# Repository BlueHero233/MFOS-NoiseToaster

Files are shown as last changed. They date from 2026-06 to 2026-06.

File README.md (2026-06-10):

# MFOS Noise Toaster

> ##### Forked from *[Tom Obvious][(https://github.com/Tom-Obvious/MFOS-NoiseToaster)]*

## Status

WIP - working out flaws from Tom's design choices

## Motivation

My first eletronics project, like, at all.
This repository is for the documentation of the changes im currently making to the Rev 6.1 of Tom's design, to better fit with at hand materials and more modern/cheaper components.
Components like the 2N5457 or the LM386N-4 arent exactly easy to find or cheap to buy, moving foward id like to do a circuit analysis of Ray's original circuit to determine if i can swap some pieces out for more common components that arent going out of production anytime soon 

## How to use this repository

This repository contains all the files necessary for building the Noise Toaster, including the synth's PCB.  
If you intend to create your own PCB, simply compress all the files located in the 'PCB/Gerber Files' directory into a .zip file and upload it to the PCB manufacturer of your choice.   
In the directories 'classic design' are all files to build the case of the Noise Toaster.    
For the front panels, I also created PCB designs, which you can upload to a manifacturer. Furthermore, there are CAD files and technical drawings (yet to come!) in the folders.   
The 'src' folder contains additional files which might be helpful.

## Project Structure
MFOS-NoiseToaster/  
  'src/' additional files and images that might be helpful for your own build   
  'classic design/'__ &rarr; all files to build the classic Noise Toaster case   
  'CAD/'
    '.FCstd' &rarr; FreeCAD files for the build    
  'front panel/'
    '.pro' &rarr; KiCAD files for front panel PCB
  'PCB/'
    'Gerber' *Generate this folder yourself!* &rarr; .zip this directory for upload to the manufacturer    
    'Noise Toaster PCB.kicad_pro' &rarr; opening the project file will also open all the subschematics and pcb
    'bom/' 
      'BoM checklist.md'  
      'interactive BOM.html' 
  'src/'
  'README.md'
  'licence.md' &rarr; CC-BY-NC-SA

## Usefull links and resources

* [Music From Outer Space](http://musicfromouterspace.com/)
* [MFOS - Noise Toaster - Documentation](http://musicfromouterspace.com/index.php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)
* [Ray Wilson - YouTube Channel](https://www.youtube.com/@Musicfromouterspace)
* [MFOS Noise Toaster Presentation - Video by Ray Wilson](https://www.youtube.com/watch?v=smFKx6gfOd0)
* [Noise Toaster in action - Video by Ray Wilson](https://www.youtube.com/watch?v=qHlyuIe3wuU)
* [Make: Analog Synthesizers by Ray Wilson](https://learning.oreilly.com/library/view/make-analog-synthesizers/9781449356200/)

---


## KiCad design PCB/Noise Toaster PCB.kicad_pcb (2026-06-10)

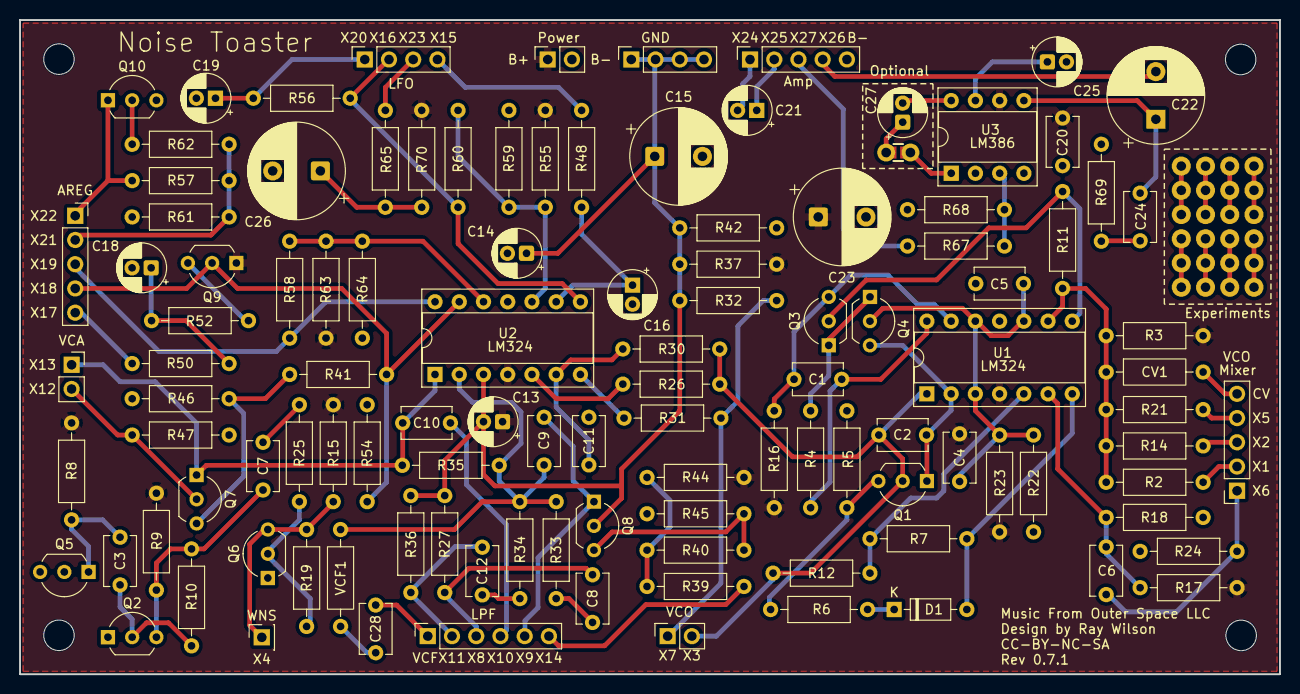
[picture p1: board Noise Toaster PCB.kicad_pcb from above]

Board: 2 copper layers, 132.1 x 68.6 mm, 113 parts (0 on the bottom side), 73 nets.

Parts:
C1: 100 pF; C_Disc_D5.1mm_W3.2mm_P5.00mm
C2: 1 nF; C_Disc_D5.1mm_W3.2mm_P5.00mm
C3, C4, C5, C7, C8, C11, C12, C20, C28: 100nF; C_Disc_D5.1mm_W3.2mm_P5.00mm
C6: 10nF; C_Disc_D5.1mm_W3.2mm_P5.00mm
C9, C10: 1nF; C_Disc_D5.1mm_W3.2mm_P5.00mm
C13, C14, C27: 10 uF; CP_Radial_D5.0mm_P2.00mm
C15, C23: 470 uF; CP_Radial_D10.0mm_P5.00mm
C16, C19, C21: 1uF; CP_Radial_D5.0mm_P2.00mm
C18: 4u7F; CP_Radial_D5.0mm_P2.00mm
C22: 220 uF; CP_Radial_D10.0mm_P5.00mm
C24: 47nF; C_Disc_D5.1mm_W3.2mm_P5.00mm
C25: 10uF; CP_Radial_D5.0mm_P2.00mm
C26: 470uF; CP_Radial_D10.0mm_P5.00mm
CV1: 100k; R_Axial_DIN0207_L6.3mm_D2.5mm_P10.16mm_Horizontal
D1: D; D_DO-35_SOD27_P7.62mm_Horizontal
J2: Power; PinSocket_1x02_P2.54mm_Vertical
J3: AREG; PinSocket_1x05_P2.54mm_Vertical
J4: LFO; PinSocket_1x04_P2.54mm_Vertical
J5: VCO; PinSocket_1x05_P2.54mm_Vertical
J6: VCO; PinSocket_1x02_P2.54mm_Vertical
J7: LPF; PinSocket_1x06_P2.54mm_Vertical
J8: VCA; PinSocket_1x02_P2.54mm_Vertical
J9: Amp; PinSocket_1x05_P2.54mm_Vertical
J10: GND; PinSocket_1x04_P2.54mm_Vertical
JP1: Jumper_Measure_Open; Jumper_2_PTH_SMD_Combo-NO
Q1, Q7, Q8, Q9: 2N5457; TO-92_Inline_Wide
Q2, Q3, Q4, Q5, Q6: 2N3904; TO-92_Inline_Wide
Q10: 2N3906; TO-92_Inline_Wide
R2: 75k; R_Axial_DIN0207_L6.3mm_D2.5mm_P10.16mm_Horizontal
R3: 270k; R_Axial_DIN0207_L6.3mm_D2.5mm_P10.16mm_Horizontal
R4, R52, R61, R62: 10k; R_Axial_DIN0207_L6.3mm_D2.5mm_P10.16mm_Horizontal
R5, R30: 2 M; R_Axial_DIN0207_L6.3mm_D2.5mm_P10.16mm_Horizontal
R6, R9, R12, R15, R17, R26, R32: 10 K; R_Axial_DIN0207_L6.3mm_D2.5mm_P10.16mm_Horizontal
R7: 300 K; R_Axial_DIN0207_L6.3mm_D2.5mm_P10.16mm_Horizontal
R8, R46: 1 M; R_Axial_DIN0207_L6.3mm_D2.5mm_P10.16mm_Horizontal
R10, R19, R41: 470 K; R_Axial_DIN0207_L6.3mm_D2.5mm_P10.16mm_Horizontal
R11: 2k; R_Axial_DIN0207_L6.3mm_D2.5mm_P10.16mm_Horizontal
R14, R55, R58, R59, R60: 100k; R_Axial_DIN0207_L6.3mm_D2.5mm_P10.16mm_Horizontal
R16: 2M; R_Axial_DIN0207_L6.3mm_D2.5mm_P10.16mm_Horizontal
R18: 15 K; R_Axial_DIN0207_L6.3mm_D2.5mm_P10.16mm_Horizontal
R21: 36k; R_Axial_DIN0207_L6.3mm_D2.5mm_P10.16mm_Horizontal
R22, R23, R37, R42, R54: 4k7; R_Axial_DIN0207_L6.3mm_D2.5mm_P10.16mm_Horizontal
R24, R25, R31, R44, R45, R47, R67: 100 K; R_Axial_DIN0207_L6.3mm_D2.5mm_P10.16mm_Horizontal
R27, R36: 47 K; R_Axial_DIN0207_L6.3mm_D2.5mm_P10.16mm_Horizontal
R33, R35: 4M7; R_Axial_DIN0207_L6.3mm_D2.5mm_P10.16mm_Horizontal
R34: 3 M; R_Axial_DIN0207_L6.3mm_D2.5mm_P10.16mm_Horizontal
R39, R40: 39 K; R_Axial_DIN0207_L6.3mm_D2.5mm_P10.16mm_Horizontal
R48, R65, R70: 3k; R_Axial_DIN0207_L6.3mm_D2.5mm_P10.16mm_Horizontal
R50: 820; R_Axial_DIN0207_L6.3mm_D2.5mm_P10.16mm_Horizontal
R56: 20k; R_Axial_DIN0207_L6.3mm_D2.5mm_P10.16mm_Horizontal
R57: 200; R_Axial_DIN0207_L6.3mm_D2.5mm_P10.16mm_Horizontal
R63, R64: 150k; R_Axial_DIN0207_L6.3mm_D2.5mm_P10.16mm_Horizontal
R68: 20 K; R_Axial_DIN0207_L6.3mm_D2.5mm_P10.16mm_Horizontal
R69: 10; R_Axial_DIN0207_L6.3mm_D2.5mm_P10.16mm_Horizontal
U1, U2: LM324; DIP-14_W7.62mm_Socket
U3: LM386; DIP-8_W7.62mm_Socket
VCF1: 3 M; R_Axial_DIN0207_L6.3mm_D2.5mm_P10.16mm_Horizontal
X4: WNS; PinSocket_1x01_P2.54mm_Vertical

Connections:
/AA: C2.1, Q1.1 (D), Q4.3 (C), U1.2 (-)
/ARG: J3.4, Q9.2 (S), R41.1, R54.2, U2.13 (-)
/Attack Release Envelope Generator/X17: J3.5, R50.2
/Attack Release Envelope Generator/X19: J3.3, R58.2, U2.14
/Attack Release Envelope Generator/X21: J3.2, R57.1, R61.2, R62.1
/Attack Release Envelope Generator/X22: J3.1, Q10.1 (E), R57.2
/Audio Amplifier/X24: C21.2, J9.1
/Audio Amplifier/X25: C21.1, J9.2
/Audio Amplifier/X26: C22.2, J9.4
/Audio Amplifier/X27: J9.3, R67.2
/FO: C10.2, J8.1, Q7.1 (D), R35.1, U2.1
/Front Panel/B: J4.2, R56.1, R60.2, U2.8
/Front Panel/X1: J5.2, R2.2
/Front Panel/X2: J5.3, R14.2
/Front Panel/X5: J5.4, R21.2
/Front Panel/X6: C6.1, J5.1, R24.1
/Front Panel/X8: C8.1, J7.3, R27.1
/Front Panel/X9: C9.1, J7.5, Q8.1 (D)
/Front Panel/X10: C10.1, J7.4
/Front Panel/X11: C12.1, J7.2, R36.2
/Front Panel/X12: J8.2, Q7.2 (S), R47.1
/Front Panel/X14: J7.6, R39.1
/Front Panel/X15: J4.4, R48.2
/Front Panel/X20: C19.1, J4.1, R56.2
/Front Panel/X23: J4.3, R65.2
/G2: C4.1, C5.1, Q4.2 (B), R22.1, R23.1, U1.3 (+), U1.10 (+), U1.12 (+)
/RMP: C2.2, J6.2, Q1.2 (S), R12.1, R26.1, R30.1, U1.1
/SQR: J6.1, R31.2, R32.2
/WNS: Q6.3 (C), R15.2, R19.1, X4.1 (Pin_1_1)
B+: C4.2, C13.1, C20.2, C23.1, J2.1, Q9.1 (D), R3.2, R8.1, R9.1, R15.1, R16.2, R17.2, R23.2, R37.1, R44.2, R55.1, R63.1, R70.2, U1.4 (V+), U2.4 (V+), U3.6 (V+)
B-: C5.2, C11.1, C14.2, C15.2, C16.2, C18.2, C19.2, C20.1, C23.2, C25.2, C26.2, J2.2, J9.5, Q2.1 (E), Q5.2 (B), Q6.1 (E), Q10.3 (C), R5.2, R18.2, R22.2, R24.2, R42.2, R45.1, R46.2, R47.2, R54.1, R59.2, R61.1, R64.1, R68.2, R69.2, U1.11 (V-), U2.11 (V-), U3.2 (-), U3.4 (GND)
GND: C13.2, C14.1, C15.1, J10.1, J10.2, J10.3, J10.4, Q8.2 (S), R27.2, R32.1, R36.1, R37.2, R42.1, U2.3 (+)
unnamed: C1.2, R4.2, U1.14
unnamed: C7.2, R25.1
unnamed: C8.2, R33.1
unnamed: C12.2, R34.1
unnamed: C18.1, R50.1, R52.1
unnamed: C22.1, C24.1, U3.5
unnamed: C24.2, R69.1
unnamed: C26.1, R65.1, R70.1
unnamed: C27.2, U3.8 (GAIN)
unnamed: C28.1, VCF1.2
unnamed: D1.2 (A), R7.2, U1.7
unnamed: D1.1 (K), R6.2
unnamed: CV1.2, J5.5
unnamed: C28.2, J7.1
unnamed: C27.1, JP1.1 (A)
unnamed: JP1.2 (B), U3.1 (GAIN)
unnamed: Q1.3 (G), R5.1, R6.1
unnamed: C3.2, Q2.2 (B), R10.2
unnamed: C7.1, Q2.3 (C), R9.2, R10.1
unnamed: Q3.2 (B), R11.2, U1.8
unnamed: C1.1, Q3.3 (C), R16.1, U1.13 (-)
unnamed: Q3.1 (E), Q4.1 (E), R4.1
unnamed: C3.1, Q5.1 (E), R8.2
unnamed: Q6.2 (B), R19.2, R25.2
unnamed: Q7.3 (G), R41.2, R46.1
unnamed: Q8.3 (G), R40.2, R45.2
unnamed: Q9.3 (G), R52.2
unnamed: Q10.2 (B), R62.2
unnamed: R31.1, U2.7
unnamed: R39.2, R40.1, R44.1
unnamed: R7.1, R12.2, U1.5 (+)
unnamed: C6.2, R17.1, R18.1, U1.6 (-)
unnamed: CV1.1, R2.1, R3.1, R11.1, R14.1, R21.1, U1.9 (-)
unnamed: C9.2, R33.2, R34.2, R35.2, U2.2 (-), VCF1.1
unnamed: R26.2, U2.5 (+)
unnamed: C11.2, R30.2, U2.6 (-)
unnamed: R55.2, R59.1, R60.1, U2.10 (+)
unnamed: C16.1, R48.1, U2.9 (-)
unnamed: R58.1, R63.2, R64.2, U2.12 (+)
unnamed: R67.1, R68.1, U3.3 (+)
unnamed: C25.1, U3.7 (BYPASS)

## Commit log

2026-05-16 Update to Kicad 10
    Changes: Moved some traces around to allow more ground fill
    [Noise Toaster PCB.kicad_pcb, Noise Toaster PCB.kicad_sch, aa.kicad_sch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]
2026-05-16 Changed Footprint
    470uF/50V Caps are 10mm not 14
    [Noise Toaster PCB.kicad_pcb]
2026-05-16 Change M4 to M3 Holes
    [Noise Toaster PCB.kicad_pcb]
2026-05-16 Added extra GND holes
    [Noise Toaster PCB.kicad_pcb]
2026-05-16 Re added VCO CV Mod pad
    [Noise Toaster PCB.kicad_pcb]
2026-05-16 Change Headers to 2.54mm
    [Noise Toaster PCB.kicad_pcb]
2026-05-23 Change TO-92 transistors to wide package to avoid shorting during soldering
    Added B- hole for speaker
    Added more vias to shorten traces
    [Noise Toaster PCB.kicad_pcb, aa.kicad_sch, areg.kicad_sch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]
2026-05-23 Change 4mm caps to 2mm pitch
    [Noise Toaster PCB.kicad_pcb]
2026-05-23 Shuffle things around
    [Noise Toaster PCB.kicad_pcb]
2026-05-24 Added VCF mod back
    [Noise Toaster PCB.kicad_pcb]
2026-05-24 Moved filtering caps closer to OPamps
    [Noise Toaster PCB.kicad_pcb]
2026-05-25 Changed Q1 Q7 Q8 Q9 Drain Source Pads
    [Noise Toaster PCB.kicad_pcb]
2026-05-25 Move footprints to allow mininum 20 mils distance between courtyards
    except for the Q3 Q4 transistor pair
    [Noise Toaster PCB.kicad_pcb]
2026-05-25 Added Holes for Gain Control
    If you add the 10uF cap to the amplifier, you can control it by adding a potentiometer between it and pin 1
    Following the internal gain equation, 30k/(150+R), you get 200 with no resistor and 20 with a 1350 ohm resistor
    Choosing a 1k pot will leave you with a gain of 26 (28db) and a 1.5k equal to 18 gain (25db), albeit with some clipping
    [Noise Toaster PCB.kicad_pcb]
2026-05-26 Fix accidental short
    Id reckon Tom tried to select these 3 traces and drag them, but the resistors didnt move along so he accidentally shorted R31, R32 and the square wave output of the VCO to the LPF
    [vco_rswg.kicad_sch]
2026-05-26 Necessary Changes to Schematic and PCB
    [Noise Toaster PCB.kicad_pcb, aa.kicad_sch, areg.kicad_sch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]
2026-05-29 Fixed grave mistake (Q10 position swapped)
    Tom forgot to mirror Q10, swapping the emitter and collectors of Q10
    Changed all the footprints of electrolytic caps to 5mm (i didnt find a single cap in my parts bin rated for 25V that was 4mm diameter)
    [Noise Toaster PCB.kicad_pcb, aa.kicad_sch, areg.kicad_sch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]
2026-06-10 Final Update
    Move power pins closer to filter caps
    [Noise Toaster PCB.kicad_pcb, Noise Toaster PCB.kicad_sch, aa.kicad_sch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]
2026-06-10 Interactive BOM

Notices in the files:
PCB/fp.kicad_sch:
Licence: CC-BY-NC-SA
